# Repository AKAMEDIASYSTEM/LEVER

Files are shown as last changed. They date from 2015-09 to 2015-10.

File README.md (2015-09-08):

# LEVER
####Experiments in electrovibration interaction strategies, inspired by Disney Research papers "Tesla Touch" and "Revel"

Here are the papers I am trying to implement here:
http://www.ivanpoupyrev.com/e-library/2010/teslatouchUIST2010.pdf

http://www.disneyresearch.com/wp-content/uploads/REVEL.pdf

###Summary
Basically, the papers describe a way to augment surfaces with _dynamically changeable tactile properties_ - a surface can change from sticky to slippery basically at will.

###Status
This work is incomplete and ongoing - for one thing, while the circuit decribed here works, I have yet to implement current-sensing feedback as described in the papers. I'm eager to accomplish this because it allows normalization of sensation across people, skin moistures, and time.

###Why I am interested
I'm interested in experimenting with this technology as applied to various notification strategies, particularly on mobile and wearable devices.
I would like to develop interactions in which a person queries a "stack" of stuff waiting for them, rather than being interrupted by a push notification.
The appeal of this technology in this application is that it's totally silent and able to be done without interrupting the person's conversation by stealing focus.
If this technology is implemented on the back of a mobile device, for example, simply rubbing a finger along the back of the phone is all that is needed to see the magnitude of my "stack."
Of course, "stack" can be many things: number of unread emails, number of to-do items, number of places of interest very near me, and so on.

###This repository
The purpose of this repo is to make my work shareable - I had a fair amount of trouble trying to go from the research paper to a safe, working circuit, and I'm hoping to save others some work.

The circuitboard isn't what I would put onto a phone - it is instead a platform for trying out different waveforms, intensities, and so on.

The intent is that you will use the board to figure out the correct implementation details and then generate your own board with a more appropriate layout.

###Requirements
You should follow the BOM pretty precisely unless you know what you are doing. The circuit is designed to work with a 9v battery and I will be trying to allow smaller/more power supplies to work with it. The microcontroller is a Teensy 3.1

###Thanks
I'm so grateful to Disney Research, Ivan Poupyrev, Olivier Bau, and others who worked on the papers for making their work available - I never would have known aobut this cool phoneomenon without their shared work! Thanks as well to nytlabs for supporting my explorations and letting me share in kind.

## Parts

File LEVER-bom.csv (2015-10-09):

Part name | Part number | Quantity | Link to store | Link to datasheet | Vendor | tested and works? | Notes:
Schottky Diodes & Rectifiers Super-Low Qrr. 600V, 3A, Rectifier | 869-QH03BZ600 | 1 | http://www.mouser.com/Search/ProductDetail.aspx?R=QH03BZ600virtualkey59040000virtualkey869-QH03BZ600 | http://www.mouser.com/ds/2/328/qh03tz600_qh03bz600-257619.pdf | Mouser | yes
5v voltage regulator | 511-L78M05CDT-TR | 1 | http://www.mouser.com/Search/ProductDetail.aspx | http://www.mouser.com/ds/2/389/CD00000447-355301.pdf | Mouser | yes
Thick film resistor, 400v rating (220k Ohm) (2012 metric size, 0805 inch size) | 71-RCV0805220KJNEA | 1 | http://www.mouser.com/Search/ProductDetail.aspx | http://www.mouser.com/ds/2/427/rcve3-537158.pdf | Mouser | yes | 1812 inch size, 4532 metric size?!
Multilayer Ceramic Capacitors MLCC - SMD/SMT 1812 2200pF 250Vac X7R 10% | 81-GA343QR7GD222KL | 1 | http://www.mouser.com/Search/ProductDetail.aspx | http://www.mouser.com/ds/2/281/Murata_CO2E_100112-558472.pdf | Mouser | yes
Thick Film Resistors - SMD 3/4watt 100Kohms 5% (2010 size) | 71-CRCW2010J-100K-E3 | 1 | http://www.mouser.com/Search/ProductDetail.aspx | http://www.mouser.com/ds/2/427/dcrcwe3-109170.pdf | Mouser | yes
Bipolar Transistors - BJT NPN Transistor High Voltage | 512-MPSA42 | 1 | http://www.mouser.com/Search/ProductDetail.aspx?R=MPSA42virtualkey51210000virtualkey512-MPSA42 | http://www.mouser.com/ds/2/149/MPSA42-196155.pdf | Mouser | yes
TRANSFORMER 18UH 1:12 SMD | 553-1978-1-ND | 1 | http://www.digikey.com/product-detail/en/0/553-1978-1-ND | http://productfinder.pulseeng.com/products/datasheets/P563.pdf | Digikey | yes | non-digikey part # is PA0367ANLT
Teensy 3.1 | 1625 | 1 | https://www.adafruit.com/products/1625 | https://www.pjrc.com/teensy/teensy31.html | Adafruit | yes
JST right angle connector | PRT-08612 | 1 | https://www.sparkfun.com/products/8612 | http://www.sparkfun.com/datasheets/Prototyping/Connectors/JST-Horizontal.pdf | Sparkfun | yes
MOSFET 2N-CH 20V 7.5A 8SOIC | FDS6911CT-ND | 1 | http://www.digikey.com/product-detail/en/FDS6911/FDS6911CT-ND/1197695 | http://www.fairchildsemi.com/datasheets/FD/FDS6911.pdf | Digikey | yes | used in prior projects, pretty sure to work
0805 resistor, 1k |  | 2 |  |  | Adafruit SMD kit | yes
0805 resistor, 33 ohm |  | 1 |  |  | Adafruit SMD kit | yes
Monochrome 1.3" 128x64 OLED graphic display | 938 | 1 | https://www.adafruit.com/products/938 | http://www.adafruit.com/datasheets/UG-2864HSWEG01.pdf | Adafruit | yes
Trimpot | 356 | 1 | https://www.adafruit.com/products/356 | none | Adafruit | yes | You can do better than this one, pinout and spacing is standard 0.1"
NEW - bourns encoder instead of trimpot | PEC11R-4215F-S0024 | 1 | https://www.digikey.com/product-detail/en/PEC11R-4215F-S0024/PEC11R-4215F-S0024-ND/4499665 | http://www.bourns.com/docs/Product-Datasheets/PEC11R.pdf | Digikey
Attempt AT DIGIKEY-ONLY BOM: (same bkg color means only one of the group is needed)
expensive tiny untested schottky diode | GB01SLT06-214 | 1 | https://www.digikey.com/product-detail/en/GB01SLT06-214/1242-1166-1-ND/3904819 | http://www.genesicsemi.com/images/products_sic/rectifiers/GB01SLT06-214.pdf | Digikey | untested
cheaper larger untested schottky | C3D02060E | 1 | http://www.digikey.com/scripts/DkSearch/dksus.dll?Detail&itemSeq=181495990&uq=635799844393152462 | http://www.cree.com/~/media/Files/Cree/Power/Data%20Sheets/C3D02060E.pdf | Digikey | untested
220k hi-v resistor (1206) | KTR18EZPJ224 | 1 | http://www.digikey.com/scripts/DkSearch/dksus.dll?Detail&itemSeq=181496989&uq=635799849725042283 | http://rohmfs.rohm.com/en/products/databook/datasheet/passive/resistor/chip_resistor/ktr.pdf | Digikey | untested
100k hi-v resistor (1206) | KTR18EZPJ104 | 1 | http://www.digikey.com/scripts/DkSearch/dksus.dll?Detail&itemSeq=181497680&uq=635799852348045544 | http://rohmfs.rohm.com/en/products/databook/datasheet/passive/resistor/chip_resistor/ktr.pdf | Digikey | untested
2200pF cap. 0805 (smaller this time!) | C2012C0G2E222J125AA | 1 | http://www.digikey.com/scripts/DkSearch/dksus.dll?Detail&itemSeq=181498260&uq=635799855811352405 | http://product.tdk.com/en/catalog/spec/mlccspec_commercial_general_midvoltage_en.pdf | Digikey | untested
10,000 pF cap, 0805 | CL21B103KEFNNNE | 1 | http://www.digikey.com/scripts/DkSearch/dksus.dll?Detail&itemSeq=181506412&uq=635799903974942525 | http://www.samsungsem.com/kr/front/downloadcms.do?fileName=S_CL21B103KEFNNNE.pdf | Digikey | untested
0.1uF cap, 0805 | CGA4J3X7T2E104M125AE | 1 | http://www.digikey.com/scripts/DkSearch/dksus.dll?Detail&itemSeq=181506445&uq=635799903974942525 | http://product.tdk.com/en/catalog/spec/mlccspec_automotive_soft_en.pdf | Digikey | untested
TRANSFORMER 18UH 1:12 SMD | 553-1978-1-ND | 1 | http://www.digikey.com/product-detail/en/0/553-1978-1-ND | http://productfinder.pulseeng.com/products/datasheets/P563.pdf | Digikey | yes | non-digikey part # is PA0367ANLT
SOT23 n-chan mosfet | 2N7002P,215 | 1 | http://www.digikey.com/product-detail/en/2N7002P,215/568-5818-1-ND/2531105 | http://www.nxp.com/documents/data_sheet/2N7002P.pdf | Digikey | untested
n-chan mosfet closer to prev version, package "SC-89, SOT-490" | FDY302NZ | 1 | http://www.digikey.com/product-detail/en/FDY302NZ/FDY302NZCT-ND/4213679 | http://www.fairchildsemi.com/datasheets/FD/FDY302NZ.pdf | Digikey | untested
mpsa-42 smd replacement, SOT-23 | MMBTA42-TP | 1 | http://www.digikey.com/product-detail/en/MMBTA42-TP/MMBTA42TPMSCT-ND/717401 | http://www.mccsemi.com/up_pdf/MMBTA42(SOT-23).pdf | Digikey | untested
mpsa-42 smd replacement, SOT-23 | MMBTA42LT3G | 1 | http://www.digikey.com/product-detail/en/MMBTA42LT3G/MMBTA42LT3GOSCT-ND/5213284 | http://www.onsemi.com/pub_link/Collateral/MMBTA42LT1-D.PDF | Digikey | untested
alternative transformer | 750032050 | 1 | http://www.digikey.com/scripts/DkSearch/dksus.dll?Detail&itemSeq=181505082&uq=635799893874631271 | http://katalog.we-online.de/pbs/datasheet/750032050.pdf | Digikey | untested

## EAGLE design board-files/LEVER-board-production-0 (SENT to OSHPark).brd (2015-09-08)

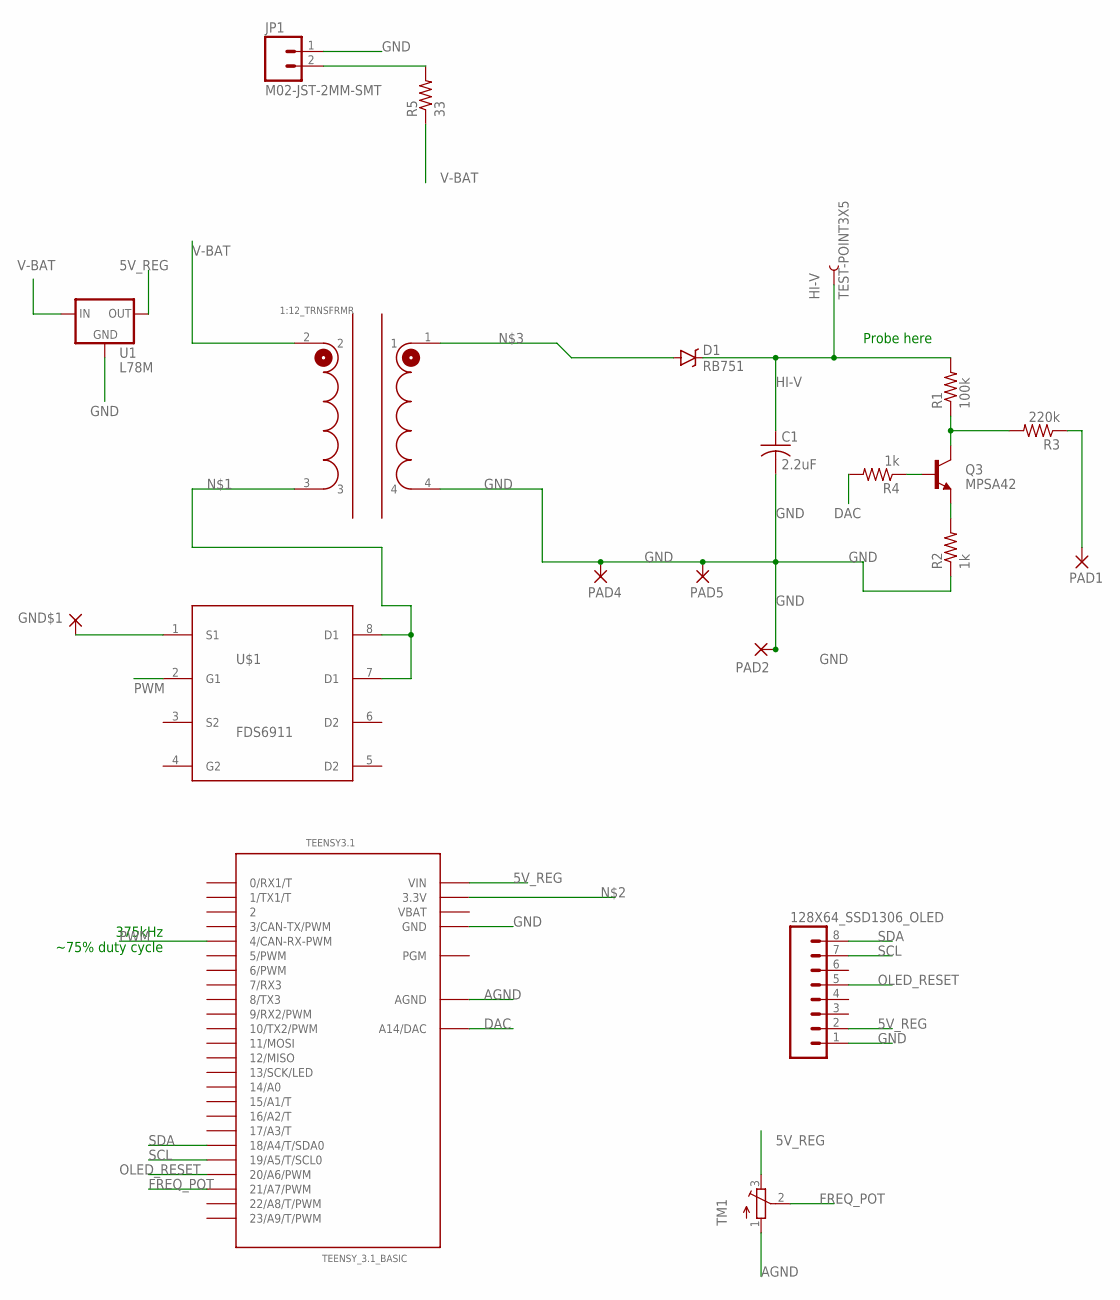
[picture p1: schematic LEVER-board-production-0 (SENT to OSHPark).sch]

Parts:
1:12_TRNSFRMR: PA0367
128X64_SSD1306_OLED: M08LOCK; 1X08_LOCK
C1: 2.2uF; C1812
D1: RB751; TO263
GND$1: WIREPADSMD5-2,5; 5-2,5
HI-V: TEST-POINT3X5; PAD.03X.05
JP1: M02-JST-2MM-SMT; JST-2-SMD
PAD1, PAD2, PAD4, PAD5: WIREPADSMD5-2,5; 5-2,5
Q3: MPSA42; TO-92
R1: 100k; R2010
R2, R4: 1k; 1206
R3: 220k; R2010
R5: 33; 1206
TEENSY3.1: TEENSY_3.1_BASIC
TM1: TRIMPOT3386; TRIM-3386
U1: L78M; DPAK
U$1: FDS6911; SO8

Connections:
5V_REG: 128X64_SSD1306_OLED.2, TEENSY3.1.VIN, TM1.3 (E), U1.3 (OUT)
AGND: TEENSY3.1.AGND, TM1.1 (A)
DAC: R4.2, TEENSY3.1.A14 (A14/DAC)
FREQ_POT: TEENSY3.1.21/A7 (21/A7/PWM), TM1.2 (S)
GND: 1:12_TRNSFRMR.4, 128X64_SSD1306_OLED.1, C1.2, GND$1.1, JP1.1 (2), PAD2.1, PAD4.1, PAD5.1, R2.1, TEENSY3.1.GND, TEENSY3.1.GND1 (GND), U1.4 (GND), U$1.1 (S1)
HI-V: C1.1, D1.1 (C), HI-V.P$1, R1.2
unnamed: 1:12_TRNSFRMR.3, U$1.7 (D1), U$1.8 (D1)
unnamed: TEENSY3.1.3.3V, TEENSY3.1.3.3V1 (3.3V)
unnamed: 1:12_TRNSFRMR.1, D1.2 (A)
unnamed: JP1.2 (1), R5.2
unnamed: Q3.1 (C), R1.1, R3.2
unnamed: Q3.3 (E), R2.2
unnamed: Q3.2 (B), R4.1
OLED_RESET: 128X64_SSD1306_OLED.5, TEENSY3.1.20/A6 (20/A6/PWM)
PAD: PAD1.1, R3.1
PWM: TEENSY3.1.4 (4/CAN-RX-PWM), U$1.2 (G1)
SCL: 128X64_SSD1306_OLED.7, TEENSY3.1.19/A5 (19/A5/T/SCL0)
SDA: 128X64_SSD1306_OLED.8, TEENSY3.1.18/A4 (18/A4/T/SDA0)
V-BAT: 1:12_TRNSFRMR.2, R5.1, U1.1 (IN)
VBAT: TEENSY3.1.VBAT

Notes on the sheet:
Probe here
375kHz ~75% duty cycle

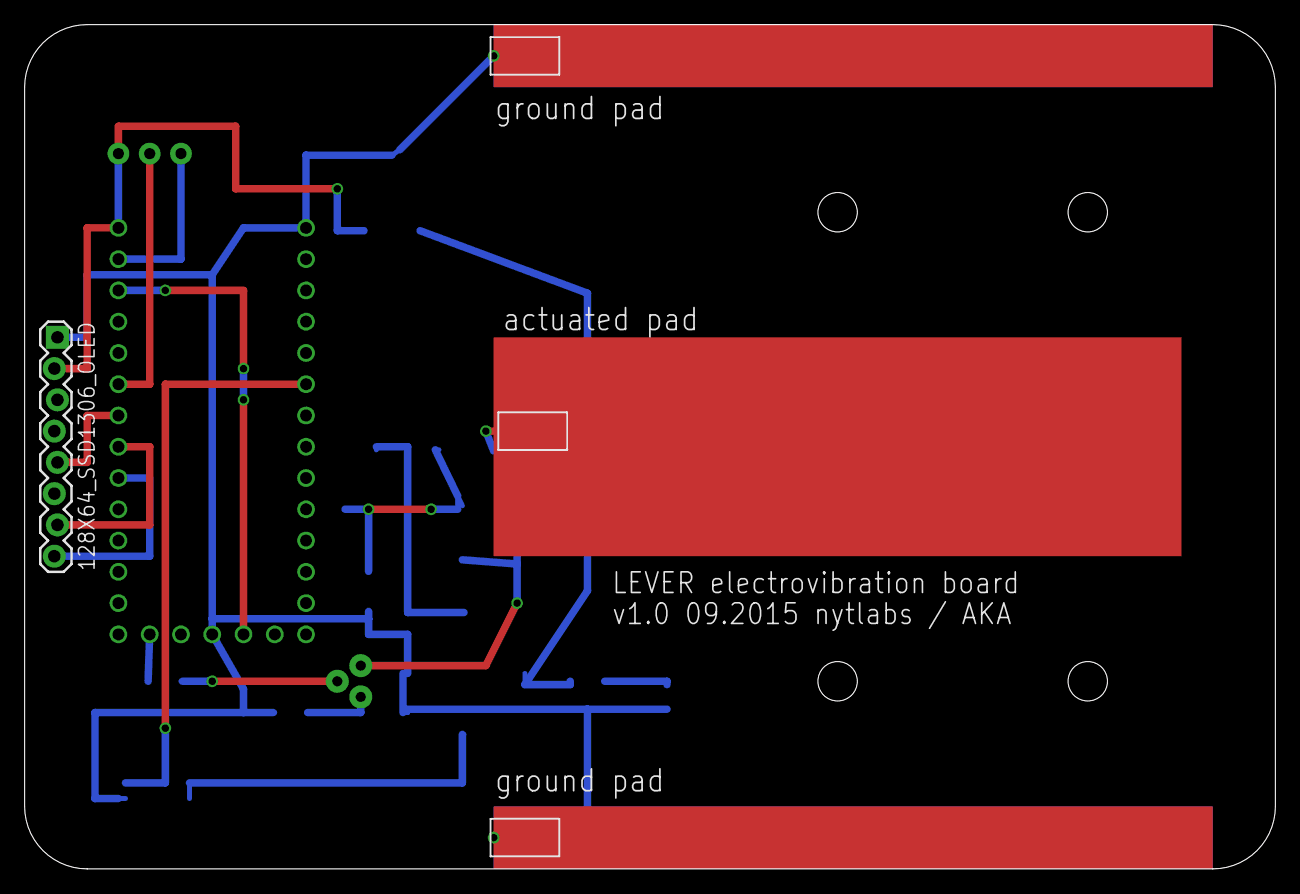
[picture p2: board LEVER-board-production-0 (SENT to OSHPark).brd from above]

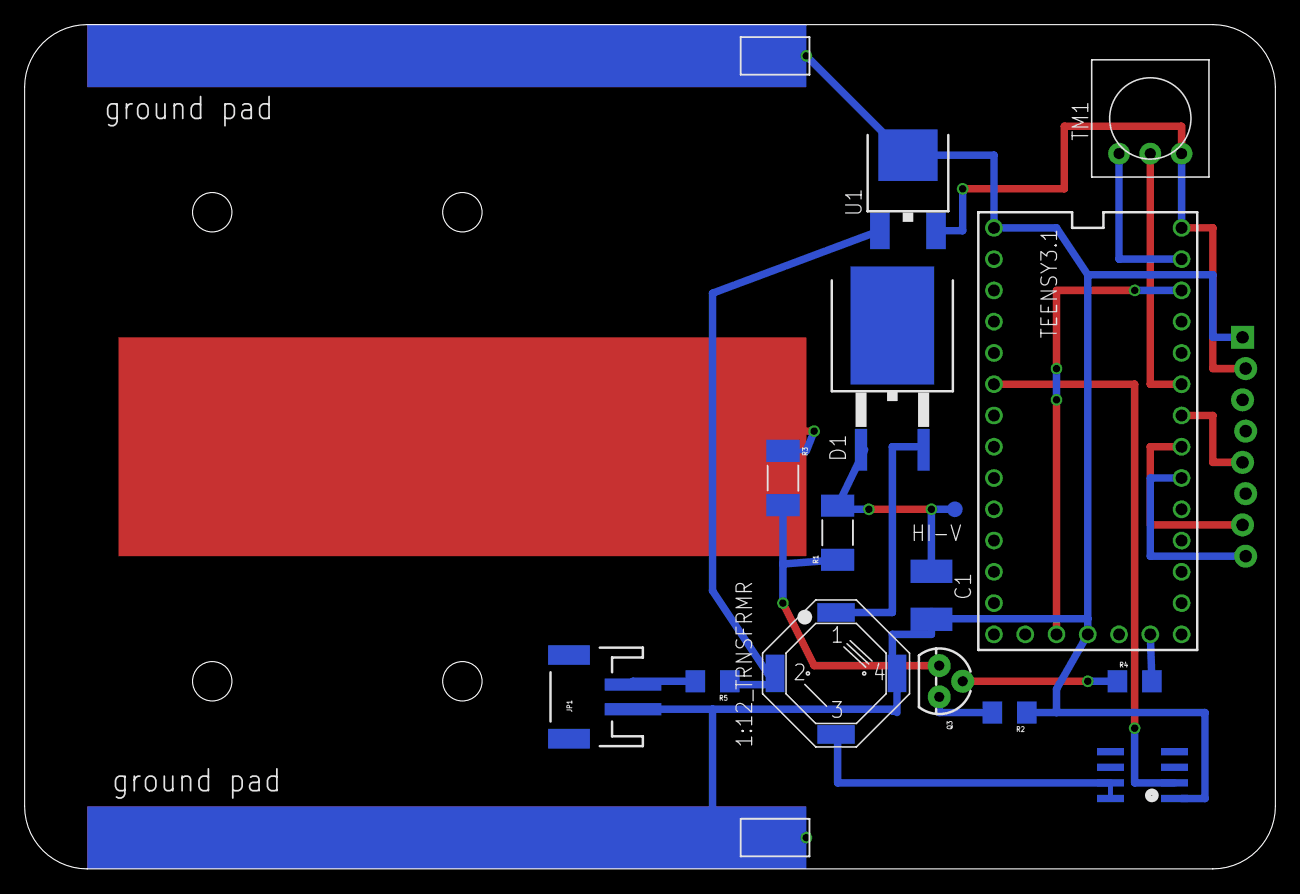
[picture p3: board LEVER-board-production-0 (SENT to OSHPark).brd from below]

Board: 2 copper layers, 101.6 x 68.6 mm, 21 parts (17 on the bottom side), 19 nets.

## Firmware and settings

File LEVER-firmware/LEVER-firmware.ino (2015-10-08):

// ENCODER VERSION
/*
// LEVER driver for implementation of REVEL and TeslaTouch papers by Disney Research
// for teensy 3.1
// Digital pin 4 sends hi-freq PWM (altered to send at 375kHz) to a boost converter circuit
// Analog pin 14 (it's a real DAC on the teensy 3.1) sends variable-freq sine wave to a hi-voltage transistor circuit
// that modulates the boosted supply voltage
// freqPot on pin A7 sets the signal frequency
// SDA on pin A4
// SCL on pin A5
// OLED_RESET on digital pin 5

// poll freqPot pin to see what freq should be
// map 0-1023 analog in to 0.0125 (about 37.5 Hz) to 0.4 (about 1000Hz), add phase
// update OLED to show approx freq and bars representing texture
// 1000hz maps to a full bar every other row (ie offset 1)
// 30 hz maps to 64 on bars, 64 off bars (ie offset 64)

// TODO: implement goal-seeking feedback to keep constant current despite changing impedances
// TODO: figure out where in teh circuit the current-sensing occurs (pretty sure we're measuring voltage drop across precision resistor?)
// TODO: figure out how an RF interface might be used, maybe RFduino serial link or BlueSmiRF?

//  phase = phase + 0.2; // about 600Hz
//  phase = phase + 0.05; // about 150Hz
//  phase = phase + 0.025; // about 75Hz
*/
// #include <Adafruit_MCP4725.h> // not yet used, for external DAC if necessary
#define ENCODER_OPTIMIZE_INTERRUPTS
#include <Encoder.h>
#include <SPI.h>
#include <Wire.h>
#include <Adafruit_GFX.h>
#include <Adafruit_SSD1306.h>

#define OLED_RESET 5
Adafruit_SSD1306 display(OLED_RESET);
#if (SSD1306_LCDHEIGHT != 64)
#error("Height incorrect, please fix Adafruit_SSD1306.h!");
#endif
#define encA A2
#define encB A3
#define encButton A1
#define pwmOut 4
#define SINE 0
#define SQUARE 1
#define SAW_DESC 2
#define SAW_ASC 3
#define NOISE 4

char* waveLabels[] = {"SINE", "SQUARE", "A_SAW", "D_SAW", "NOISE"};
char* modeLabels[] = {"FREQ", "AMP", "WAVE", "DUTY"};
volatile int encMode = 0;
volatile boolean shouldUpdate = true;

float minFreq = 0.016 * 1000.0; // 0.0125 is too low for some people to feel, trying 0.016 now
float maxFreq = 0.4 * 1000.0;

float minDuty = 0.3;
float maxDuty = 0.95;
float dutyCycle = 0.3;

float minAmpl = 0.0;
float maxAmpl = 2000.0;
float DACamplitude = 2000.0;

int waveType = 0; // sine, square, saw descending, saw ascending, noise
#define waveMax 4
#define waveMin 0

float phase = 0.01;
float twopi = 3.14159 * 2;
float phaseOffset = 100; //just an initial condition, this used to be 0.05

long lastFreq = 200; // middle-to-low end of the 0-1023 range
long lastWave = 0; // sine
long lastAmp = 1023; // full amplitude
long lastDuty = 10; // low end of duty cycle
long newFreq = 200;
long newWave = 0;
long newAmp = 1023;
long newDuty = 10;

long newPosition = 0;
long lastPosition = 0;

Encoder myEnc(encA, encB);

void setup() {
  // 0 - 4095 pwm values if res set to 12-bit
  analogWriteResolution(12);
  analogWriteFrequency(pwmOut, 375000);
  pinMode(pwmOut, OUTPUT);
  pinMode(encButton, INPUT_PULLUP); // MODE switch
  attachInterrupt(encButton, encButtonPress, RISING);
  display.begin(SSD1306_SWITCHCAPVCC, 0x3D);  // initialize with the I2C addr 0x3D (for the 128x64)
  display.setTextSize(1);
  display.setTextColor(WHITE);
  display.display();
}

void loop() {
  long newPosition = myEnc.read();
  long delta = newPosition - lastPosition;

  if (abs((delta)) != 0) {
    // calculate delta, toggle updateDisplay
    // increment the appropriate mode-position by the delta?
    switch (encMode) {
      case 0: // FREQ
        newFreq += delta;
        lastFreq = newFreq;
        phaseOffset = constrain(floatmap(newFreq, 0, 1023, minFreq, maxFreq), minFreq, maxFreq);
        break;
      case 1: // AMP
        newAmp += delta;
        lastAmp = newAmp;
        DACamplitude = constrain(floatmap(newAmp, 0.0, 1023.0, minAmpl, maxAmpl), minAmpl, maxAmpl);
        break;
      case 2: // WAVE
        newWave = int(floor((newWave + delta/2))) %4; // want this to change every encoder detent, which is 4 counts... still not working great
        // for example, this only changes every 24 detents...
        // oh! encoder is PEC11R-4215F-S0024
        // meaning 24 detents and 24 pulses per 360º
        // so each detent is only 1 and not 4
// encoder seems to advance +/- 1 or 2 each turn (from observation)

        
        lastWave = newWave;
        waveType = constrain(map(newWave, 0, 3, waveMin, waveMax), waveMin, waveMax);
        break;
      case 3: // DUTY
        newDuty += delta;
        lastDuty = newDuty;
        dutyCycle = constrain(floatmap(newDuty, 0.0, 1023.0, minDuty, maxDuty), minDuty, maxDuty);
        break;
      default:
        newFreq += delta;
        lastFreq = newFreq;
        phaseOffset = constrain(floatmap(newFreq, 0, 1023, minFreq, maxFreq), minFreq, maxFreq);
        break;
    }
    shouldUpdate = true;
    lastPosition = newPosition;
  }

  analogWrite(pwmOut, int(4096 * dutyCycle)); // duty cycle should have been dynamically calculated before here

  calculateFeedback(); // this doesn't exist yet

  float DACval = 0;
  phase = phase + (phaseOffset / 1000.0);
  if (phase >= twopi) {
    phase = 0;
  }

  switch (waveType) {
    case SINE:
      DACval = sin(phase) * DACamplitude + 2050.0;
      // 2050.0 is DC offset?
      break;
    case SQUARE:
      // if phase > pi then 1 else 0
      (phase > twopi / 2) ? (DACval = (DACamplitude / maxAmpl) * 4095.0) : (DACval = 0.0);
      break;
    case SAW_DESC:
      // phase itself is linearly ramping
      DACval = floatmap(phase, 0, twopi, 0.0, 1.0) * (DACamplitude / maxAmpl) * 4095.0;
      break;
    case SAW_ASC:
      // phase itself is linearly ramping
      DACval = floatmap(phase, 0, twopi, 1.0, 0.0) * (DACamplitude / maxAmpl) * 4095.0;
      break;
    case NOISE:
      (random(0, 9) > 4.5) ? (DACval = (DACamplitude / maxAmpl) * 4095.0) : (DACval = 0.0);
      break;
    default:
      DACval = sin(phase) * DACamplitude + 2050.0;
      break;
  }

  DACval = 4095.0 - DACval;
  analogWrite(A14, (int)DACval);

  if (shouldUpdate) {
    updateDisplay(delta);
    shouldUpdate = false;
  }

  shouldUpdate = false;
}

void encButtonPress() {
  encMode++;
  encMode %= 4;
  shouldUpdate = true;
}

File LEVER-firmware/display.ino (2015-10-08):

void updateDisplay(long pos) {
  display.clearDisplay();
  for (int i = 0; i < display.width(); i++) {
    int barOffset = int(map(phaseOffset, maxFreq, minFreq, 0, display.width() / 2));
    if (i % barOffset <= barOffset / 2) {
      // fill in the column if it's not
      display.drawLine(i, 0, i, display.height() - 28, WHITE);
    }
  }

  display.setCursor(2, display.height() - 24);
  display.print(modeLabels[encMode]);
  
  display.setCursor(42, display.height() - 24);
  display.print(waveLabels[waveType]);
  
  display.setCursor(82, display.height() - 24);
  int freq = int(map(phaseOffset, minFreq, maxFreq, 37.5, 1200));
  display.print(int(freq));
  
  display.setCursor(2, display.height() - 12);
  display.print(DACamplitude / maxAmpl);
  
  display.setCursor(42, display.height() - 12);
  display.print(int(dutyCycle * 100));
  display.print("%");
  
  display.setCursor(82, display.height() - 12);
  display.print(pos);
  display.display();

}

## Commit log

2015-09-08 adding extant firmware and board files
    [LEVER-board-production-0 (SENT to OSHPark).brd, LEVER-board-production-0 (SENT to OSHPark).sch, LEVER-board-production-0.brd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]
2015-09-08 added display code which failed to add before for some reason
    [display.ino]
2015-09-08 added current BOM
    [LEVER-bom.csv]
2015-09-10 added manual pwm modulation - discovered pwn can go all the way down to 30% and still generate ~160v, excellent. Affords new, rubbery feeling at low-end of freq and pwm scales
2015-09-14 fixed offset and amplitude scaling problems - sensor board is a little shaky, which affects screen update rate, which affects circuit. will have to stabilize those sigs (more decoupling, probably) an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
    [LEVER-firmware.ino, display.ino]
2015-09-23 added aux firmware for testing v1 of OSH board
2015-09-24 swapping triangle waveform for NOISE, still needs to be tested a bit
    [LEVER-boardtesting.ino, LEVER-firmware.ino]
2015-09-24 stabilizing display upon startup, added measured real-freq ranges to boardtesting firmware
2015-09-29 amplitude now works properly, after inversion right before writing to the DAC. However, adding updateDisplay() logic to all the other pots failed, slowing the whole loop down to an unusable extent. T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
    [LEVER-firmware.ino]
2015-10-05 updating firmware to accept button-and-encoder, should make screen more stable and UI easier
2015-10-07 moving encoder firmware over to main sketch
2015-10-08 still trying to make encoder work with WAVE selection, everything else working well
2015-10-08 got encoder working acceptably and initial conditions set better
2015-10-09 updated bom
    [LEVER-bom.csv]
2015-10-14 boardtesting firmware inconsequential change

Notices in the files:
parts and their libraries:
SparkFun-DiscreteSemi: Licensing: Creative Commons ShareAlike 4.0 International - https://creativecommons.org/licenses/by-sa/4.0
